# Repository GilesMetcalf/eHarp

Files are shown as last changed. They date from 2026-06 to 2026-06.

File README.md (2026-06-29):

# Lughnasadh eHarp
This is the ongoing eHarp project. 

## feature summary
The eharp is a full-featured MIDI controller that offers the following functions:
- Up to 32 notes that can be played
- Fully polyphonic
- A choice of 23 different scales (modes)
- A choice of MIDI channels
- Transposition from -6 to +6 intervals. Essentially any key in the octave.
- Selectable octave settings from -3 to +3
- 11 selectable velocity settings
- Pitch and Bend controls
- Sustain pedal input
- Multi-level menu system
- Self-calibration to compensate for background light levels
- Several self-diagnostic features

## Architecture and principles
The eHarp is based on a scanned matrix of small lasers to detect an interruption to the beam (by sticking fingers into the beam!). The interruption is detected by a phototransistor which feeds an baseline-compensated analogue level amplifier and a digital comparator. A microcontroller (a Raspberry Pi Pico 2) runs CircuitPython code to detect the interruption, identify which laser is on at the time, makes appropriate adjustments depending on the selected scale, velocity, bend value and transposition, and them emits MIDI messages to whatever device is on the end. 

The lasers are small 5mW diodes (such as are used in laser pointers), scanned sequentially by the microcontroller. Only "active" diodes are scanned, so any which are not part of the scale, or that have been identified as blocked or faulty by the calibration routines are not illuminated and are skipped from the scan. This reduces any latency in generating notes, as well as preventing spurious notes playing.

## Boot and run sequences
### Boot up and calibration
On initially powering the eHarp up, the (numerous) I/O ports are initialised and the baseline offset output set to a default value of approximately 150mV. A flag is set to prevent any MIDI output (this stops random notes playing during calibration). A nice splash screen is displayed for a few seconds. This serves no purpose other than being flash, and can be aborted by pressing any button on the menu panel. The software twiddles it's little digital thumbs while this is displayed.
Once the splash expires, the eHarp drops into it's automated calibration routine. There are two elements to this. Firstly the baseline offset is adjusted to allow for the current ambient light by reading the sensor output (post amplification) with no lasers on. The offset voltage is adjusted to approximately 30-50mV above zero to give a bit of stability. 
Following the offset adjustment, all the lasers are scanned to check that they are producing an output and that the sensor is detecting them. (This assumes that there are no fingers in the way for this part!) Any which fail for any reason (poor and failing output - always a danger with cheap laser diodes! - misalignments or blockages, etc.) are marked as inactive and removed from normal scans. 
Finally, the main menu is displayed and the main scan routines are initiated.

### Run cycle
The run cycle essentially runs forever, and consists of three elements:
- The menu buttons are scanned. If any have been pressed, the menu subsystem executes whatever menu option is selected. This might be to change to a submenu, reset a state value (such as scale or key), or execute a calibration or diagnostic function. Once the action has been carried out, the menu returns to the parent level (or the main level, depending where it is in the heirarchy), and normal scanning continues.
- The laser matrix is scanned. All the available cells (0 to 31) are processed in sequence, and for each cell if the selected scale array and active note array both indicate that the cell is valid, the laser is illuminated. The sensor input is read, and if the beam is interrupted the current MIDI state for that note is checked. There are several possible outcomes at this stage:
  - The beam is not interrupted and the note is not active; do nothing and move on to the next cell.
  - The beam is not interrupted but the note was active; emit a <samp>NoteOff</samp> MIDI message.
  - The beam is interrupted and the note was active; do nothing and move on to the next cell.
  - The beam is interrupted and the note was not active; emit a <samp>NoteOn</samp> MIDI message.
- Once the cell has been  processed, the laser is turned off and the sequence moves to the next cell.
- Finally, once all the cells have been processed, the MIDI state (bend/mod controls and octave selection buttons) are scanned. Any changes are detected and state variables set accordingly. The bend and mod controls are analogue inputs from a joystick and are captured using the Pico's built-in ADC.

### MIDI generation
For each MIDI note generation event, before the <samp>NoteOn</samp> event is emitted, some adjustments and enhancements are needed. The <samp>NoteOn</samp> event contains several parameters:
- The actual note number, which is calculated from the cell number (0 to 31) plus the MIDI offset to get to the actual note (C3 for the bottom note). This is then appended with the transposition value (-6 to +6) and the octave value to give the required note.
- The velocity value (how hard the 'key' has been struck). This comes from the selected velocity value
- The MIDI channel number. This comes from the selected channel value.
  
On top of that, there are some MIDI control events that also need to be emitted, although these are not directly associated with a specific note:
- If the Bend control value has changed, a <samp>PitchBend</samp> event is emitted.
- If the Mod control value has changed, a <samp>ControlChange(1)</samp> event is emitted.
- If the Sustain pedal is pressed, a <samp>ControlChange(64)</samp> event is emitted with a parameter of 127 (sustain on).
- If the Sustain pedal is released, a <samp>ControlChange(64)</samp> event is emitted with a parameter of 0 (sustain off).

*My thanks also to Adam Metcalf for the original inspiration, as well as much sage advice during the design and build of this project (and not laughing at my terrible electronics!)*

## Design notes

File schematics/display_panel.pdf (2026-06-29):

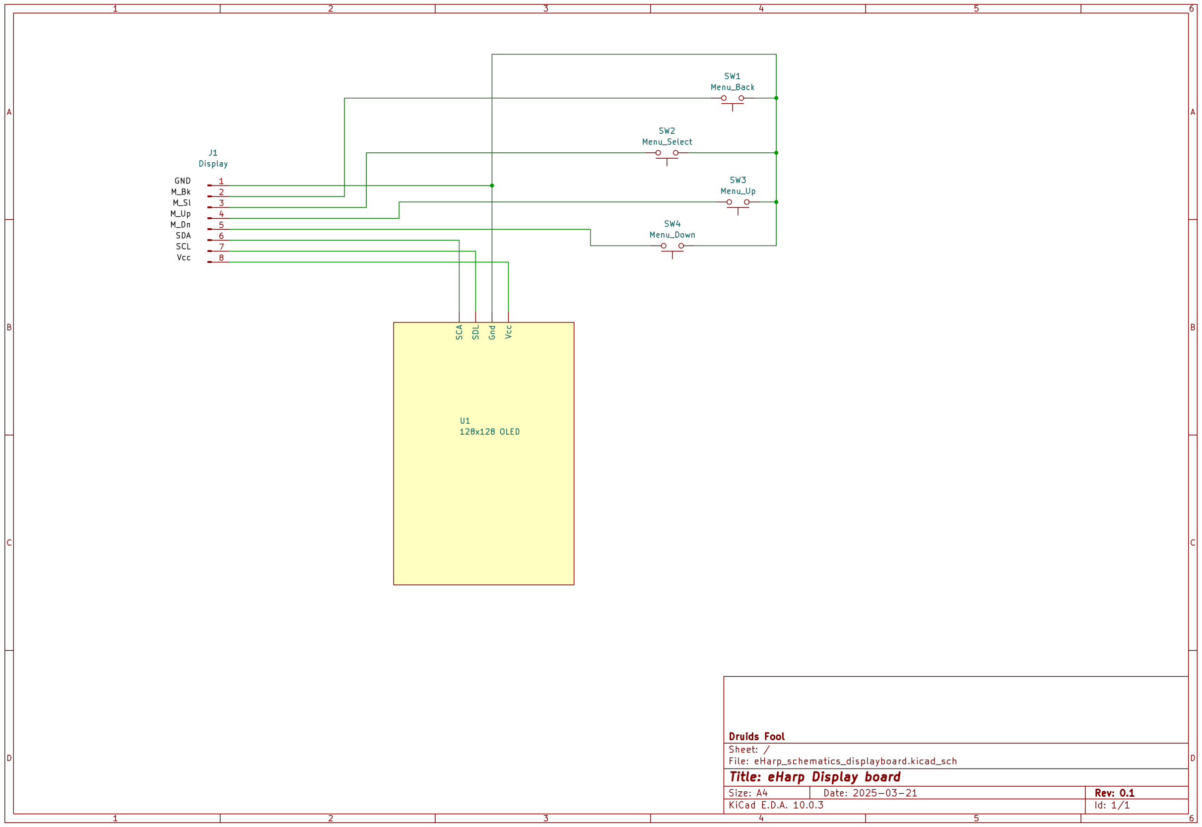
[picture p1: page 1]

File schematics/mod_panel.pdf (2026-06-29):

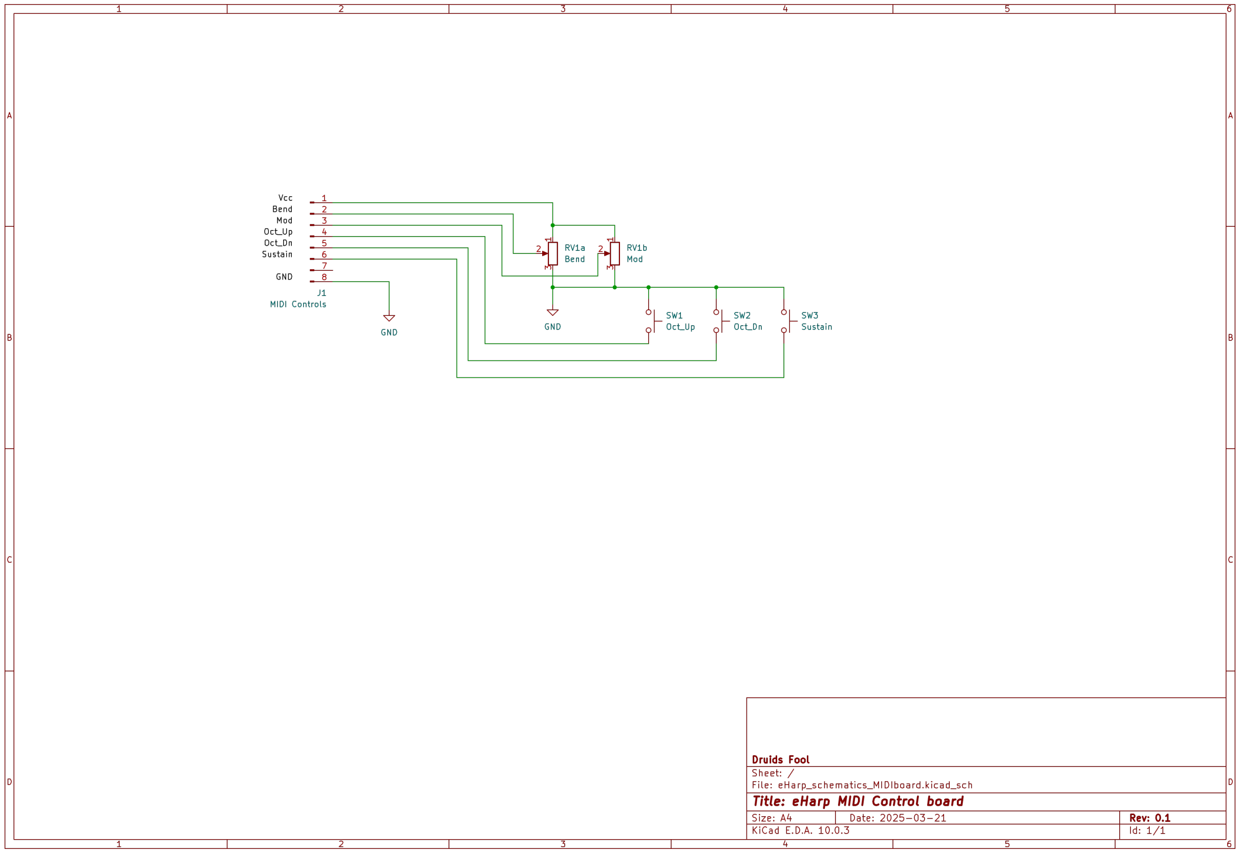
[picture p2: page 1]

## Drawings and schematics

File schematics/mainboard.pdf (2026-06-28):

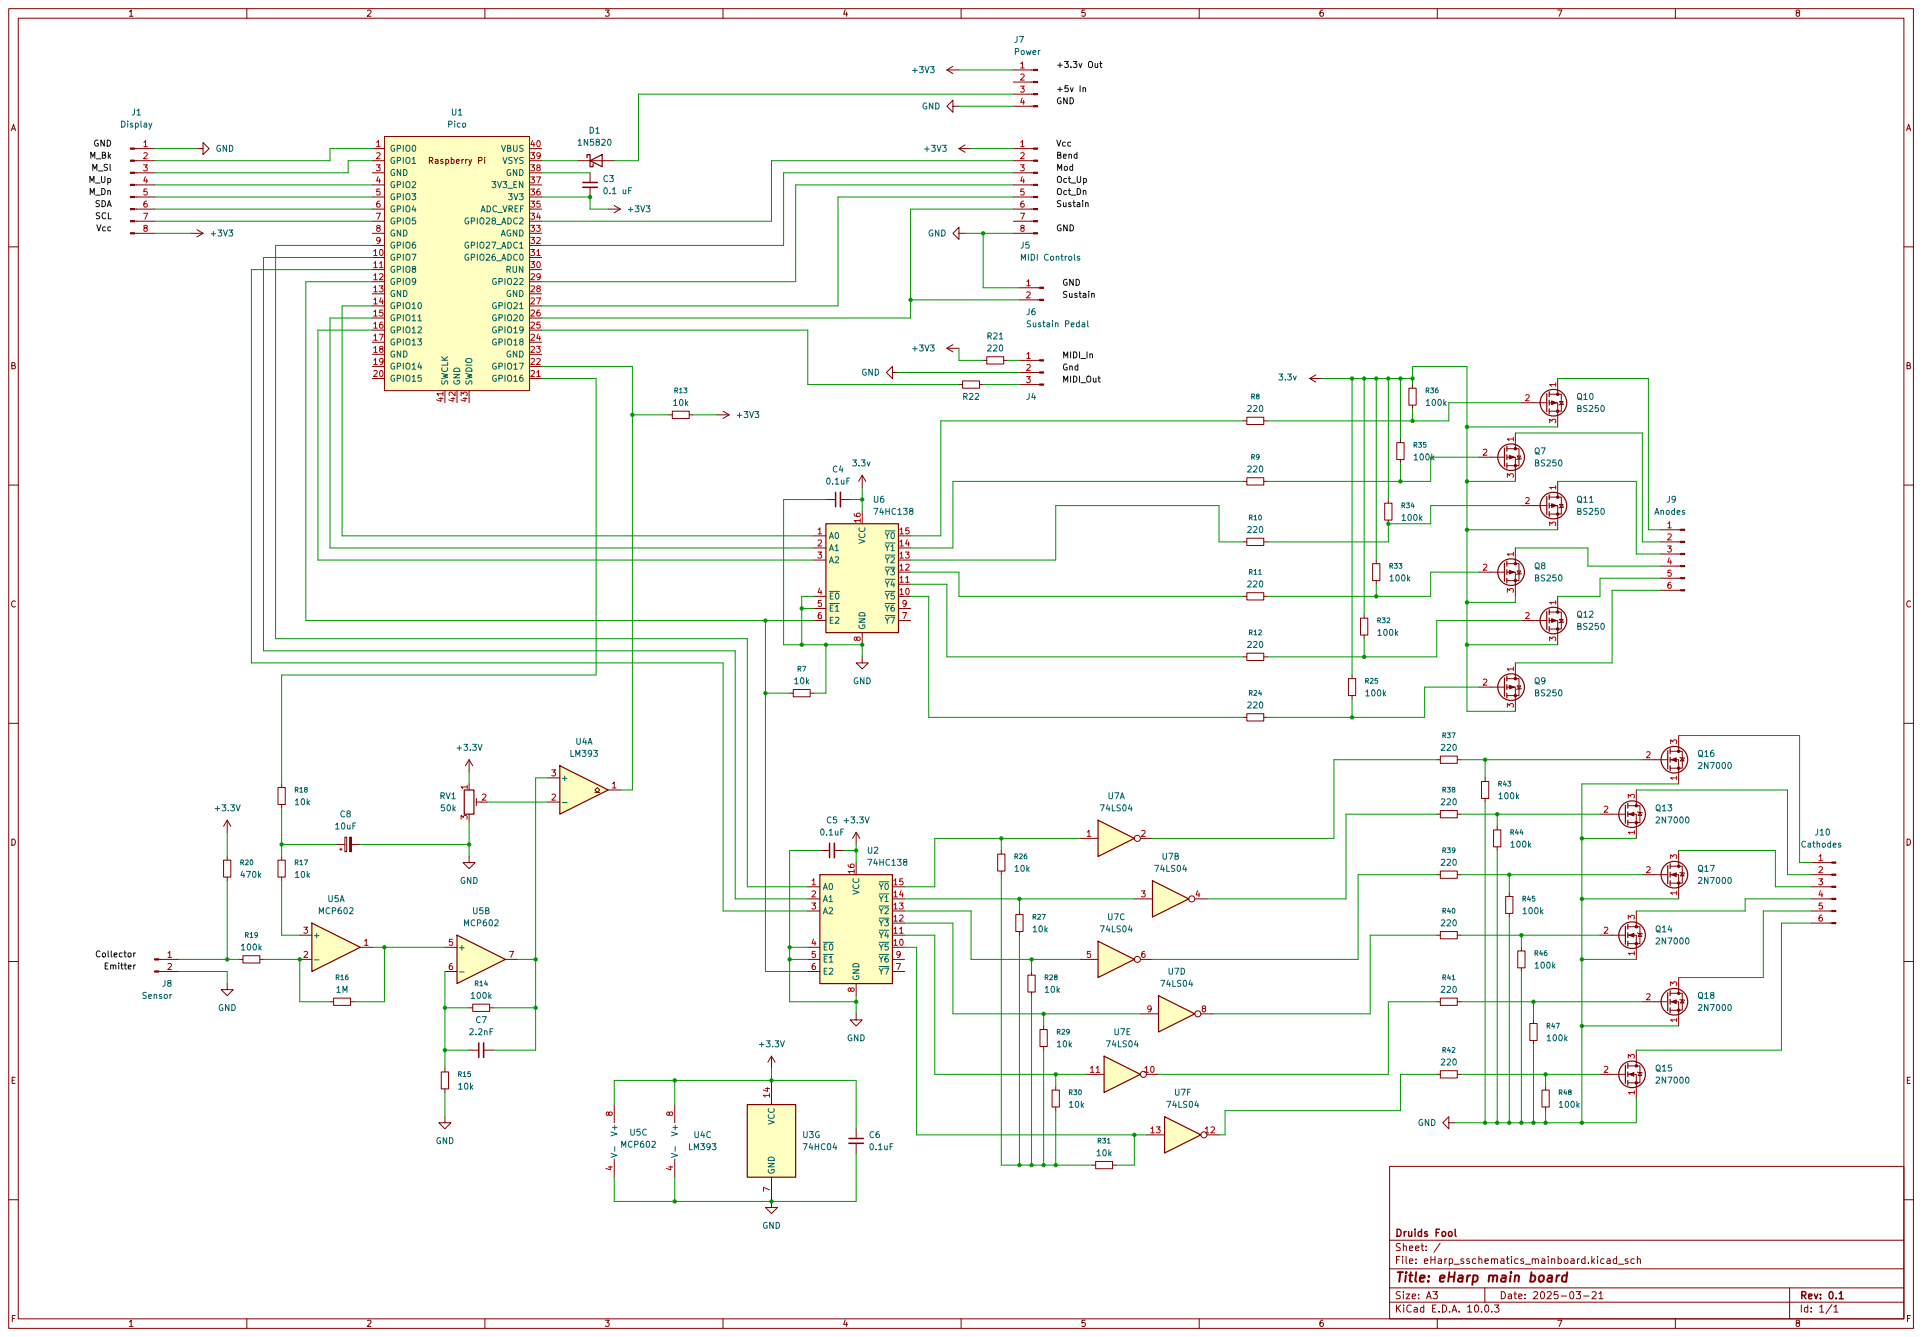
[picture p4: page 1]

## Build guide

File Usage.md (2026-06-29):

# Using the eHarp

## IMPORTANT SAFETY NOTE!!!
This instrument uses lasers. Lots of lasers!
Although the laser diodes are relatively low power (<5mW), they are still sufficient to cause eye injury if stared into. DO NOT LOOK DIRECTLY INTO THE LASER ARRAY!

## The menus
There are a number of menus available that allow the user to select various settings for playing, as well as giving access to some diagnostic and calibration features.

### Scales menu
There are 23 different scales or modes that can be selected from the **Scales** menu:
- Chromatic
- Major
- Minor
- Lydian
- Aeolian
- Super Locrian
- Augmented
- Bebop Dominant
- Blues
- Dorian
- Double Harmonic
- Enigmatic
- Flamenco
- Gypsy
- Half Diminished
- Harmonic Major
- Harmonic Minor
- Istrian
- Locrian
- Lydian Augmented
- Lydian Diminished
- Mixolydian
- Phrygian

Selecting one of these modes will restrict the MIDI output to only notes within that scale. Other notes and incidentals will not play.

### Tuning menu
The eHarp is naturally tuned to C (that is, the lowest note is C3). The tuning menu will allow transposition to any other key in semitones. That will also apply to any mode or scale that has been selected.

### Channel menu
This control selects the MIDI channel that messages are output on. By default, this is set to channel 0, but any channel up to 10 can be selected. Currently, it is not possible to select "all", although this may be implemented in the future.

### Velocity menu
MIDI velocity is a numerical representation of how hard a note is hit. Since this is not something that can be physically implemnted for interrupting a light beam, the **Velocity** menu allows the user to manually select one of 11 different velocity settings between 8 (really soft) and 127 (really hard). The default value is 64.

### Diagnostics menu
The **Diagnostics** menu provides access to a number of further features for recalibrating the eHarp, and some options that can be used when diagnosing issues or setting up the eHarp.

- _Calibration:_  This option reruns the automated calibration and valid note checks. It can be used if notes stop working, or notes play unasked. 
- _Slow Scan:_  This performs a slow scan of all the lasers in the array 5 times. It can be used to determine if all the laser diodes are working, as well as for setting the threshold for the comparator. MIDI messages will not be generated during this process, so no notes will play.
- _Single Step:_  Each laser is lit one at a time. The *"menu up"* and *"menu down"* buttons will step on to the next laser in the array. The *"menu back"* button will abort this process and return to the **Diagnosics** menu. MIDI messages will not be generated during this process, so no notes will play.
- _Mute Lasers:_  This option turns off all the lasers and precvents scanning for up to 1 minute. This is useful when setting the comparator threshold. At the end of the minute, or if any menu button is pressed before that, the process is aborted and the user returned to the **Diagnostics** menu.

Once all diagnostics have been completed, pressing the *"menu back"* button will return to the main menu, and normal operations will continue.

## The MIDI mod and octave controls
The **MOD** panel provides controls for changing the notes wheil playing.

### Octave buttons
The *Octave up* and *Octave down* buttons allow the user to transpose the output up or down full octaves (up to three octaves up or down from the nornal value, or between C1 to C6 for the lowest note). Scale/mode choice and any transposition remain unchanged when the octave is changed. 

### Mod/Bend control
The joystick performs three functions when playing. In one direction (marked on the panel) it bends the note playing up or down. In this fashion it performs in the same way as a Pitch Bend wheel on a normal keyboard.
In the orthogonal direction, the joystick acts as a Mod wheel, applying any modification (such as filter changes or vibrato) defined by the MIDI instrument being controlled. The **Mod** control is slightly different from the **Bend** control in that it works in the same way whichever way it is pushed.

Finally, If the joystick is pushed in, this turns on the sustain in the same way as using a sustain pedal.

## Connections
Three connections are provided.

### USB connection
The USB connection is used for both powering the eHarp, as well as providing a MIDI-over-USB communications with the MIDI instrument being used. This might be a DAW or a VST host, but equally it might be a hardware instrument such as a synth. Some sort of MIDI routing might be required (such as MIDIDash) to make sure that the messages appear where they should. This is dependent on your setup.

### MIDI output
There is also a 5-pin DIN standard MIDI connector in the schematic. I have not yet configured this in the software, but this will eventually mirror the USB MIDI output for more conventional connections.

### Sustain pedal
There is a 1/4-inch jack socket for a standard normally-off sustain pedal.

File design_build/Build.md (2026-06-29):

# Building the eHarp

This is not a detailed construction guide, more a loose description of the approach I took with the prototype!

## The body
The main body of the eHarp is built from four layers of ply. Two sheets of 600x1220mm ply were obtained from my local DIY store; a sheet of 12mm and a sheet of 20mm. I could get two 
body sections from each sheet (see cutting_plan.svg for the layout). These can be cut out with a jigsaw; I used a *big* bandsaw (you won't be able to do it with a small benchtop bandsaw!). It is also easier to make a template from some light ply for marking this out. The template has a couple of functions; it ensures that all your ply sections are the same shape and size, and it also comes in useful later one when you are aligning all those little laser diodes in the array. More on that later.
The 12mm sections form the inner core of the body. Before gluing them together, cut out the rectangular openings marked in red on the diagram for the controls - note that the larger opening is on one section only! Glue and clamp.
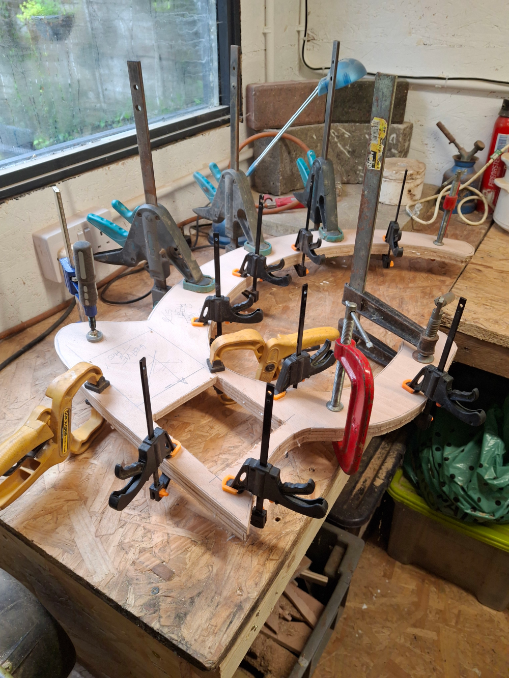
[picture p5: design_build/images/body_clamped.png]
(image) Body glued and clamped


Cut out the outer sections from the 20mm ply in the same way. Put them aside until later.
Once the core is glued, cut out a section for the laser array on the longer arm (keep the bit you cut out - you'll need it later), and a section for the sensor at the end of the shorter arm. Again, these are marked in red on the diagram. Use a router to cut channels for the cables for the laser array and the sensor to the electronics bay (the larger opening) in the core section.

The outer sections of 20mm ply can now be glued on and clamped. It is worth laying some cord into the routed channels before doing this. It makes pulling the cables through a lot easier, and prevents a lot of poking with bits of stiff wire and swearing later! Just be careful not to catch the cord between the layers of ply and gluing it permanently into place!
Once everything is glued and dried, the edges can be routed round, any nasty gaps filled, and the whole thing sanded smooth. Finish it with whatever finish takes your fancy. I did mine with a metallic red paint, and a light dusting of an iridescent spray. The whole thing was then given several coats of a hard-wearing varnish (I know how much things can get knocked about!).

## The laser array
This is where that bit you saved (you *did* save it, didn't you?) comes in. It will need to be cut down a little further to leave you with a curved section about 2cm wide on the inside of the curve. Cut a couple of cm off each end as well to allow space to fit it later. Measure the length of the outside curve of the piece, allow another centimeter or so for space, and divide the remainder by 32. This will give you the spacing of the individual laser diodes. Use a pair of dividers to mark off the locations along the edge. 
Draw lines at *exactly* 90 degrees to the edge toward the inner curve. These are the drill guides that you will be using to make the holes for the diodes. Also draw a line along the exact middle of the inner curve.
Measure the diameter of the diode module (mine were 6mm) and using a *sharp* drill bit 0.5mm wider, drill holes from inside curve to outside curve along the guidelines for all 32 diodes. Use a pillar drill, and it's probably worth making a little jig to help with this. You won't be able to do it accurately with a hand drill!

How you assemble the array is up to you, but in my case I found it easiest to take it one diode at a time, testing, aligning and securing each one before moving on to the next one. The diodes I used were 3.3v ones, and you will need a suitable power supply or battery with crocodile clips so that you can power up each diode before soldering it in to anything.
Remember I said that that plywood template would come in useful? Clamp or use double-sided tape to affix the drilled plywood array section to the long arm of the template, and attach a small target (a small round bit of wood, or a pen cap) to the centre of the end of the short arm. Now, for each laser:
- Connect it to the supply. Make sure that the polarity is correct and watch your eyes!
- Check the focus and brightness. When buying in bulk, some diodes can be pretty dim and often out of focus. The lens end can be twisted to focus the beam.
- Put the diode in place in it's hole. If you drilled accurately it should be fairly close to your target. You can wiggle it a bit to get it properly aimed.
- Once aimed, fix it in place with a small drop of thin superglue. Apply the glue to the back, *not* the front (you get glue on the lens otherwise and obscure the beam - don't ask me how I know this!).

The array can be wired. The leads from the diodes are very thin and flimsy, so it is worth keeping them as short as possible, and don't connect them directly to any flying leads for connecion to the main board. Provide some fixed connection points next to the diodes and use those. I found some small copper tacks that worked admirably. If using tacks like this, drill the wood with a small drill and push them in - don't hammer them! Complete the wiring with ribbon cable, and leave enough to reach the main board easily.

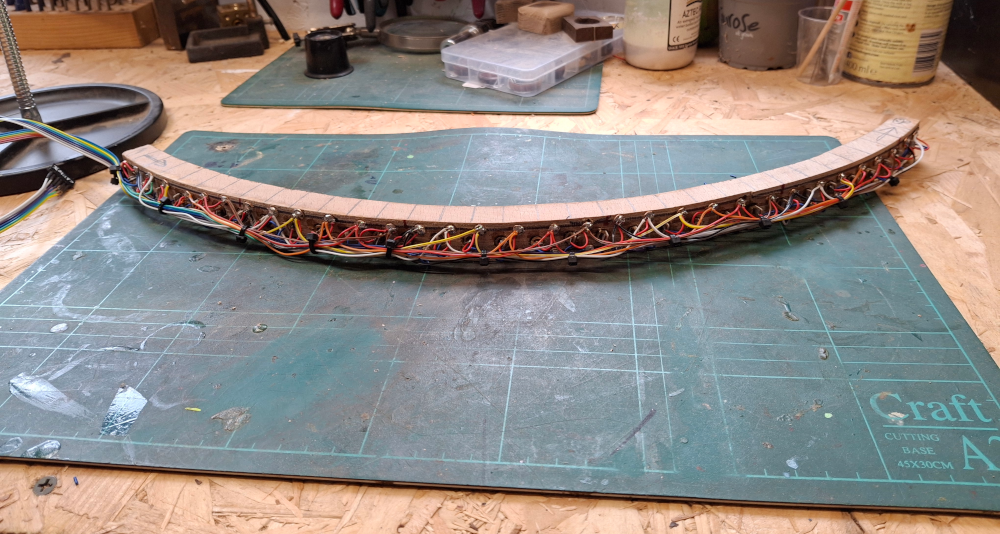
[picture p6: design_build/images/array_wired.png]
(image) Laser array diodes in place

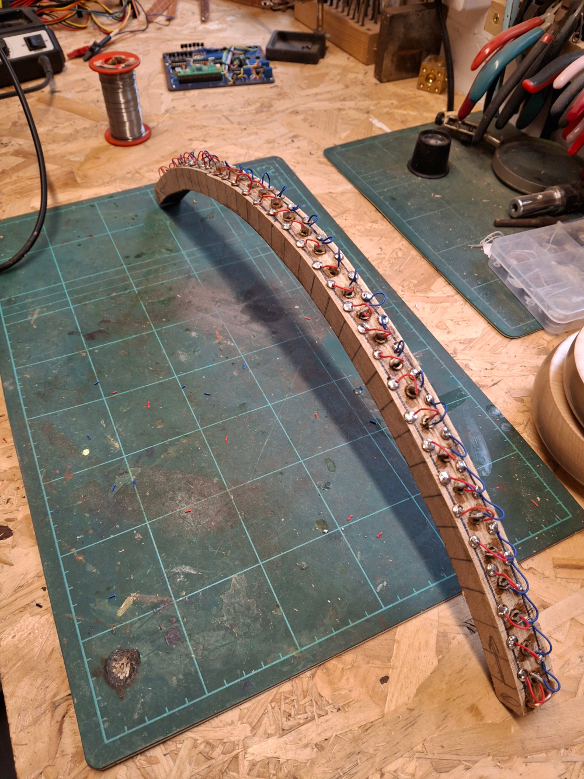
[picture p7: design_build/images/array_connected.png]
(image) Laser array wired up


## The sensor
The laser sensor is a bit simpler to put together. It was made from a stack of four units cut from 6mm clear acrylic (there is a template in the drawings). Once cut, the segments were glued together using UV-curing glue, and clamped before curing to remove any air bubbles. Once glued, the stack was sanded down to 8000 grit and then polished with cutting compound to get a glassy finish.
In order to maximise light capture it is worth putting some sort of reflective finish on all faces except the front-facing curved face. I used silver leaf, but a reflective silver paint will work too. Mask off the front face before gilding/painting to prevent anything getting on that face.

Once the acrylic block is finished, drill a 6mm hole from one of the flat sides to the centre of the segment. Shorten the leads of a PT334-6C phototransistor and solder a length of coaxial cable on (braid to emitter, core to collector). Use heat-shrink sleeving to insulate the joints. You could use normal cable. but the levels are very low and you may pick up a lot of noise. Coax will reduce this.
Insert the phototransistor into the hole you drilled and secure in place with UV-curing glue.

## The panels
There are three control panels, a menu/display one, a bend/mod and octave selection one, and a connector panel for the interfaces and power. The construction principles are the same for each.
Each panel is made from two layers of 2mm acrylic, laser-cut to shape. All the cutting guides for these are in the diagrams. I have also provided the labels for these panels here. These can be printed out and sandwiched between the layers of acrylic.
I built the circuitry for the panels on stripboard (as this is a prototype). It would be nicer to user proper PCBs.
Again, flying ribbon cables should be attached with sufficient length to reach the electronics bay.

## The main board
All the circuitry was built on one prototyping board (well, it was a prototype!) that fits into the electorincs bay. Again, it would be nicer to use a proper PCB, but this has been through many iterations and I did not want a huge pile of useless boards cluttering up my workshop!
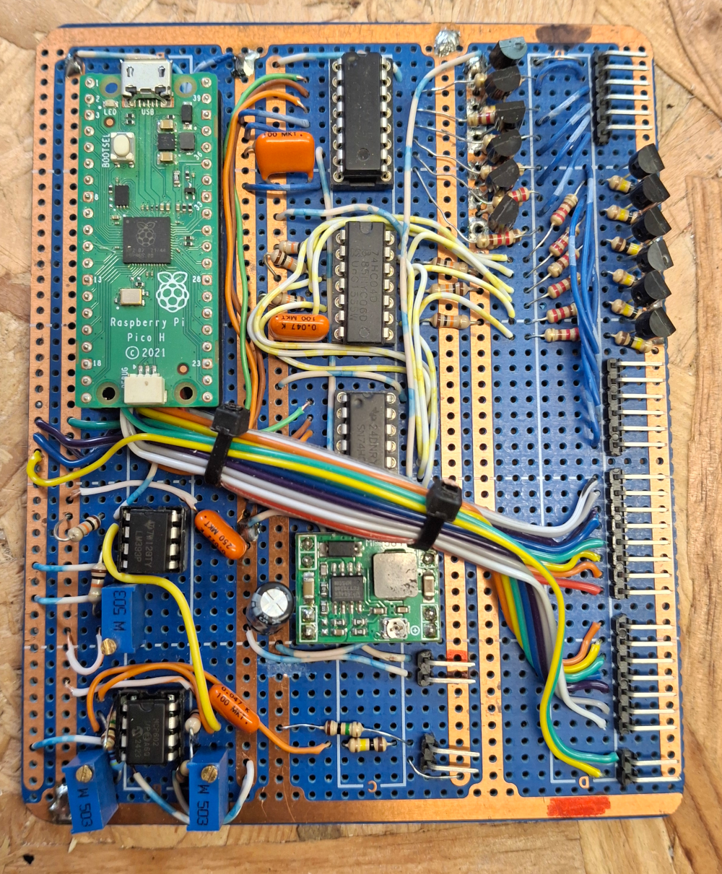
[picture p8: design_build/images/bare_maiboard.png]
(image) The mainboard


## Assembly
The sensor was placed in the short arm of the eHarp, and glued in place using 2-part epoxy.

The cables for the laser array were drawn through the channel using the previously placed cord, and then the array located in place so that the lowest note (first laser in the array) is towards the base of the harp, and the highest at the top end of the arm. The array is lightly placed initially, as it may need to be repositioned slightly to aim them at the sensor correctly.
The various panels are put in place and secured with small brass screws. All the leads are brought out to the electronics bay (which is now sprouting a bewildering nest of cables! You *did* mark them before putting everything in place, didn't you?).

Finally, the main board is connected and nestled in the electronics bay. 
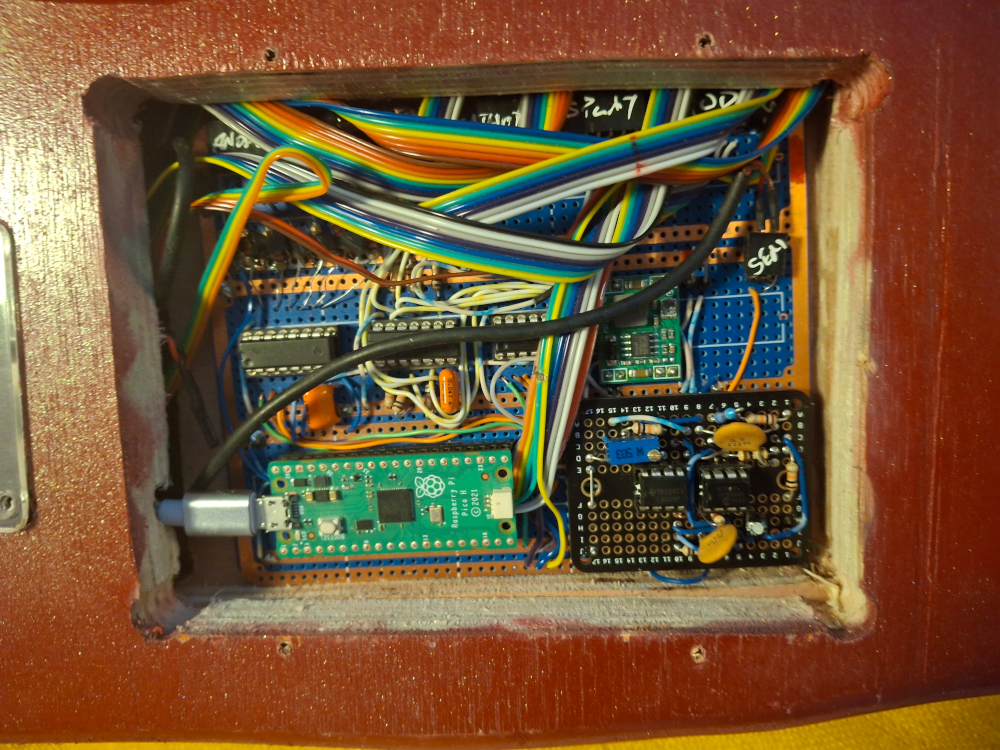
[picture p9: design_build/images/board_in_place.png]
(image) The mainboard in place

Connect up the USB cable to a supply and let it boot up. Once it has finished booting, use the Slow Scan option in the Diagnostics menu to finish aligning the laser array. It can be pressed into place, and secured with a drop of glue if necessary (it should be a tight push fit, and not need glue).

## Final adjustment
There is one small adjustment that will be needed, and this will require an oscilloscope or a logic analyser. This should be attached to the output of the LM393 comparator (U5 on the schematic). Select Mute Lasers from the Diagnostics menu (this will turn off all the lasers) and set RV1 to give a LOW output.
Now select Slow Scan from the Diagnostics menu and tweak RV1 to give a HIGH output for each laser.

[body_clamp]: https://github.com/GilesMetcalf/eHarp/tree/main/design_build/images/body_clamped.png "(image) Body glued and clamped"
[array_wired]: https://github.com/GilesMetcalf/eHarp/tree/main/design_build/images/array_wired.png "(image) Laser array diodes in place"
[array_connected]: https://github.com/GilesMetcalf/eHarp/tree/main/design_build/images/array_connected.png "(image) Laser array wired up"
[mainboard]: https://github.com/GilesMetcalf/eHarp/tree/main/design_build/images/bare_maiboard.png "(image) The mainboard"
[board_placed]: https://github.com/GilesMetcalf/eHarp/tree/main/design_build/images/board_in_place.png "(image) The mainboard in place"

You're all done! All that is needed is a cover over the electronics bay. I used a small piece of 3mm ply, coloured to match the rest of the body, and secured with small brass screws.
Connect it to your favourite DAW or VST host and enjoy!

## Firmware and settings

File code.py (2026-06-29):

# eHarp in CircuitPython

# +-------------------------------+
# |   *** eHarp v2.0 Project ***  |
# |                               |
# | Author:         Gil Metcalf   |
# | Code version:   2.10.8        |
# | Date:           28-Jun-2026   |
# | Licence :       GPL v3.0      |
# +-------------------------------+

import board
import displayio
import terminalio
from adafruit_display_text import label
import adafruit_displayio_sh1107
import busio
import digitalio
import time
import analogio
import pwmio
import usb_midi
import adafruit_midi
from adafruit_midi.note_on import NoteOn
from adafruit_midi.note_off import NoteOff
from adafruit_midi.pitch_bend import PitchBend
from adafruit_midi.control_change import ControlChange
import config

# +------------------------------+
# | Constants and menu constants |
# +------------------------------+

# IO ports (menu buttons)
button_up = digitalio.DigitalInOut(board.GP2)
button_up.direction = digitalio.Direction.INPUT
button_up.pull = digitalio.Pull.UP
button_dn = digitalio.DigitalInOut(board.GP3)
button_dn.direction = digitalio.Direction.INPUT
button_dn.pull = digitalio.Pull.UP
button_bck = digitalio.DigitalInOut(board.GP0)
button_bck.direction = digitalio.Direction.INPUT
button_bck.pull = digitalio.Pull.UP
button_sel = digitalio.DigitalInOut(board.GP1)
button_sel.direction = digitalio.Direction.INPUT
button_sel.pull = digitalio.Pull.UP

# IO ports (MIDI controls)
button_oct_up = digitalio.DigitalInOut(board.GP22)
button_oct_up.direction = digitalio.Direction.INPUT
button_oct_up.pull = digitalio.Pull.UP
button_oct_dn = digitalio.DigitalInOut(board.GP21)
button_oct_dn.direction = digitalio.Direction.INPUT
button_oct_dn.pull = digitalio.Pull.UP
button_stn = digitalio.DigitalInOut(board.GP19)
button_stn.direction = digitalio.Direction.INPUT
button_stn.pull = digitalio.Pull.UP
mod_in = analogio.AnalogIn(board.A1)
bend_in = analogio.AnalogIn(board.A2)

# IO ports (note scanning)
row_s0 = digitalio.DigitalInOut(board.GP10)
row_s0.direction = digitalio.Direction.OUTPUT
row_s1 = digitalio.DigitalInOut(board.GP11)
row_s1.direction = digitalio.Direction.OUTPUT
row_s2 = digitalio.DigitalInOut(board.GP12)
row_s2.direction = digitalio.Direction.OUTPUT
col_s0 = digitalio.DigitalInOut(board.GP6)
col_s0.direction = digitalio.Direction.OUTPUT
col_s1 = digitalio.DigitalInOut(board.GP7)
col_s1.direction = digitalio.Direction.OUTPUT
col_s2 = digitalio.DigitalInOut(board.GP8)
col_s2.direction = digitalio.Direction.OUTPUT
scan_in = digitalio.DigitalInOut(board.GP17)
scan_in.direction = digitalio.Direction.INPUT
scan_in.pull = digitalio.Pull.UP
lsr_enbl = digitalio.DigitalInOut(board.GP9)
lsr_enbl.direction = digitalio.Direction.OUTPUT

# IO ports (analogue input control)
baseline_in = analogio.AnalogIn(board.A0)
baseline_out = pwmio.PWMOut(board.GP18, frequency=500)

# Scanning constants
num_notes = config.NUM_NOTES
output_enable = False # Disable MIDI note generation for setup and calibration

# Menu handling constants
button_pressed = [0,0,0,0]
last_button_state = [0,0,0,0]

# State values
state_menu = 0
state_scale = 0
state_tune = 6
state_channel = 1
state_octave = 0
state_velocity = 6

# Menus
scales = [
  "Chromatic",
  "Major",
  "Minor",
  "Lydian",
  "Aeolian",
  "Super Locrian",
  "Augmented",
  "Bebop Dominant",
  "Blues",
  "Dorian",
  "Double Harmonic",
  "Enigmatic",
  "Flamenco",
  "Gypsy",
  "Half Diminished",
  "Harmonic Major",
  "Harmonic Minor",
  "Istrian",
  "Locrian",
  "Lydian Augmented",
  "Lydian Diminished",
  "Mixolydian",
  "Phrygian"
]

tuning = ["-6", "-5", "-4", "-3", "-2", "-1", "0", "1", "2", "3", "4", "5", "6"]

channel = ["0", "1", "2", "3", "4", "5", "6", "7", "8", "9", "10"]

velocity = ["8", "16", "24", "32", "48", "64","72", "80", "96", "112", "127"]

system_menu = ["Calibration", "Slow Scan", "Single Step", "Mute lasers"]

# Mapping scales
scale_map = [
  [1,1,1,1,1,1,1,1,1,1,1,1,1,1,1,1,1,1,1,1,1,1,1,1,1,1,1,1,1,1,1,1,1,1,1,1],  # Chromatic
  [1,0,1,0,1,1,0,1,0,1,0,1,1,0,1,0,1,1,0,1,0,1,0,1,1,0,1,0,1,1,0,1,0,1,0,1],  # Major
  [1,0,1,1,0,1,0,1,0,0,1,1,1,0,1,1,0,1,0,1,0,0,1,1,1,0,1,1,0,1,0,1,0,0,1,1],  # Minor
  [1,0,1,0,1,0,1,1,0,1,0,1,1,0,1,0,1,0,1,1,0,1,0,1,1,0,1,0,1,0,1,1,0,1,0,1],  # Lydian
  [1,0,1,1,0,1,0,1,1,0,1,0,1,0,1,1,0,1,0,1,1,0,1,0,1,0,1,1,0,1,0,1,1,0,1,0],  # Aeolian
  [1,1,0,1,1,0,1,0,1,0,1,0,1,1,0,1,1,0,1,0,1,0,1,0,1,1,0,1,1,0,1,0,1,0,1,0],  # Super Locrian
  [1,0,0,1,1,0,0,1,1,0,0,1,1,0,0,1,1,0,0,1,1,0,0,1,1,0,0,1,1,0,0,1,1,0,0,1],  # Augmented
  [1,0,1,0,1,1,0,1,0,1,1,1,1,0,1,0,1,1,0,1,0,1,1,1,1,0,1,0,1,1,0,1,0,1,1,1],  # Bebop Dominant
  [1,0,0,1,0,1,1,1,0,0,1,1,1,0,0,1,0,1,1,1,0,0,1,1,1,0,0,1,0,1,1,1,0,0,1,1],  # Blues
  [1,0,1,1,0,1,0,1,0,1,1,0,1,0,1,1,0,1,0,1,0,1,1,0,1,0,1,1,0,1,0,1,0,1,1,0],  # Dorian
  [1,1,0,0,1,1,0,1,1,0,0,1,1,1,0,0,1,1,0,1,1,0,0,1,1,1,0,0,1,1,0,1,1,0,0,1],  # Double Harmonic
  [1,1,0,0,1,0,1,0,1,0,1,1,1,1,0,0,1,0,1,0,1,0,1,1,1,1,0,0,1,0,1,0,1,0,1,1],  # Enigmatic
  [1,1,0,0,1,1,0,1,1,0,0,1,1,1,0,0,1,1,0,1,1,0,0,1,1,1,0,0,1,1,0,1,1,0,0,1],  # Flamenco
  [1,0,1,1,0,0,1,1,1,0,1,0,1,0,1,1,0,0,1,1,1,0,1,0,1,0,1,1,0,0,1,1,1,0,1,0],  # Gypsy
  [1,0,1,1,0,1,1,0,1,0,1,0,1,0,1,1,0,1,1,0,1,0,1,0,1,0,1,1,0,1,1,0,1,0,1,0],  # Half Diminished
  [1,0,1,0,1,1,0,1,1,0,0,1,1,0,1,0,1,1,0,1,1,0,0,1,1,0,1,0,1,1,0,1,1,0,0,1],  # Harmonic Major
  [1,0,1,1,0,1,0,1,1,0,0,1,1,0,1,1,0,1,0,1,1,0,0,1,1,0,1,1,0,1,0,1,1,0,0,1],  # Harmonic Minor
  [1,1,0,1,1,0,1,1,0,0,0,0,1,1,0,1,1,0,1,1,0,0,0,0,1,1,0,1,1,0,1,1,0,0,0,0],  # Istrian
  [1,1,0,1,0,1,1,0,1,0,1,0,1,1,0,1,0,1,1,0,1,0,1,0,1,1,0,1,0,1,1,0,1,0,1,0],  # Locrian
  [1,0,1,0,1,0,1,0,1,1,0,1,1,0,1,0,1,0,1,0,1,1,0,1,1,0,1,0,1,0,1,0,1,1,0,1],  # Lydian Augmented
  [1,0,1,1,0,0,1,1,0,1,0,1,1,0,1,1,0,0,1,1,0,1,0,1,1,0,1,1,0,0,1,1,0,1,0,1],  # Lydian Diminished
  [1,0,1,0,1,1,0,1,0,1,1,0,1,0,1,0,1,1,0,1,0,1,1,0,1,0,1,0,1,1,0,1,0,1,1,0],  # Mixolydian
  [1,1,0,1,0,1,0,1,1,0,1,0,1,1,0,1,0,1,0,1,1,0,1,0,1,1,0,1,0,1,0,1,1,0,1,0]   # Phrygian
]

# MIDI constants and variables
midi = adafruit_midi.MIDI(midi_out=usb_midi.ports[1], out_channel=state_channel)
current_octave = 0
last_octave_up = 0
last_octave_down = 0
last_sustain = 0
last_mod = 0
last_bend = 0
note_active = [0 for i in range(num_notes)]
note_valid = [1 for i in range(num_notes)]

# Display constants
displayio.release_displays()
i2c = busio.I2C(board.GP5, board.GP4)  # Update pins if needed
display_bus = displayio.I2CDisplay(i2c, device_address=0x3C)
display = adafruit_displayio_sh1107.SH1107(display_bus, width=config.DISPLAY_WIDTH, height=config.DISPLAY_HEIGHT, display_offset=config.DISPLAY_OFFSET)
display.rotation = config.DISPLAY_ROTATION
display_window = config.DISPLAY_WINDOW


# +----------------------+
# | Laser scan functions |
# +----------------------+

def selectMuxChannel(s0, s1, s2, mux):
  s0.value = (mux & 0x01) > 0  # Set LSB
  s1.value = (mux & 0x02) > 0  # Set second bit
  s2.value = (mux & 0x04) > 0  # Set third bit

def selectLaser(cell):
  # Select and turn on the selected laser
  row = cell % config.NUM_ROWS
  col = cell // config.NUM_ROWS
  lsr_enbl.value = 0
  selectMuxChannel(row_s0, row_s1, row_s2, row)
  selectMuxChannel(col_s0, col_s1, col_s2, col)
  lsr_enbl.value = 1

def set_baseline():
  lsr_enbl.value = 0
  for _ in range(config.CALIBRATION_SCANS):
    base_mv = baseline_in.value / config.DCMV_RATIO
    time.sleep(config.BASE_SETTLE)
    if base_mv > config.BASE_OFFSET:
      offset = base_mv - config.BASE_OFFSET
      baseline_out.duty_cycle = int(offset * config.DCMV_RATIO)

def checkForValidNotes():
  global note_valid, note_active, output_enable
    # Reset everything
  note_active = [0 for i in range(num_notes)]
  note_valid = [1 for i in range(num_notes)]
    # Loop around the array and look for blocked/non-working lasers
    # Non-working notes will be ignored in scans so that they don't play continuously.
  output_enable = False
  for _ in range(config.CALIBRATION_SCANS):
    for cell in range(0,num_notes):
      selectLaser(cell)
      time.sleep(config.LASER_SETTLE) # Settle time
      current_sensor = scan_in.value
      if current_sensor == config.NOTE_ON_LOGIC:   # Laser is not reaching the sensor
        note_valid[cell] = 0    # Mark the note as dead
      else:
        note_valid[cell] = 1    # Mark the note as working
  # Back to main menu
  output_enable = True
  go_back()

def calibrate():
  set_baseline()
  checkForValidNotes()

def scanMatrix():
  # global note_valid, state_scale
  for cell in range(0,num_notes):
      if scale_map[state_scale][cell] == 1 and note_valid[cell] == 1:
        selectLaser(cell)
        time.sleep(config.LASER_SETTLE) # Settle time
        current_sensor = scan_in.value
        if (current_sensor == config.NOTE_ON_LOGIC and note_active[cell] == 0):
          note_active[cell] = 1
          testScale(cell)
        elif (current_sensor != config.NOTE_ON_LOGIC and note_active[cell] == 1):
          note_active[cell] = 0
          releaseNote(cell)

def slow_scan():
  # Slowly cycle round all lasers
  global output_enable
  output_enable = False
  for _ in range(0,config.SLOW_SCAN_COUNT):
    for cell in range(0,num_notes):
      selectLaser(cell)
      time.sleep(config.SLOW_SCAN_SPEED)
  # Back to main menu
  output_enable = True
  go_back()

def single_step():
  # Manually step through lasers
  global last_button_state
  this_step = 0
  while True:
    if button_up.value == 0 and last_button_state[0] == 0:
      last_button_state[0] = 1
      this_step += 1
      if this_step > num_notes - 1:
        this_step = num_notes - 1
    if button_dn.value == 0 and last_button_state[1] == 0:
      last_button_state[1] = 1
      this_step -= 1
      if this_step < 0:
        this_step = 0
    if button_bck.value == 0 and last_button_state[3] == 0:
      last_button_state[3] = 1
      break
    selectLaser(this_step)
    time.sleep(0.5) # Allow time to release the button!
    last_button_state[0] = 0
    last_button_state[1] = 0
    last_button_state[3] = 0
    lsr_enbl.value = 0  # Turn off any lasers
  go_back()

def mute_lasers():
  # Turn lasers off for up to 1 minute
  global output_enable
  output_enable = False
  lsr_enbl.value = 0
  start_time = time.monotonic()
  while time.monotonic() - start_time < config.MAX_MUTE_TIME:  # Press any button to continue...
    if not button_up.value:
      break
    if not button_dn.value:
      break
    if not button_sel.value:
      break
    if not button_bck.value:
      break
    time.sleep(0.05)
  output_enable = True
  lsr_enbl.value = 1


# +--------------------------+
# | Scale and MIDI functions |
# +--------------------------+
def set_scale(index):
  global state_scale
  state_scale = index
  scale_menu.pointer = index
  go_back()

def set_tune(index):
  global state_tune
  state_tune = index
  tuning_menu.pointer = index
  go_back()

def set_velocity(index):
  global state_velocity
  state_velocity = index
  velocity_menu.pointer = index
  go_back()

def set_channel(index):
  global state_channel
  state_channel = index
  channel_menu.pointer = index
  go_back()


# +----------------------------+
# | Menu and display functions |
# +----------------------------+

# Classes for menu handling
class Menu:
  def __init__(self, title, items, pointer = 0):
    self.title = title
    self.items = items
    self.pointer = max(0, min(pointer, len(items) - 1))
class MenuItem:
  def __init__(self, text, action=None, submenu=None):
    self.text = text
    self.action = action
    self.submenu = submenu


# Menu configuration
scale_menu = Menu(
  "Scales",
  [MenuItem(
    scale_name, action=lambda idx=i: set_scale(idx))
    for i, scale_name in enumerate(scales)
  ], state_scale)

tuning_menu = Menu(
  "Tuning",
  [MenuItem(
    tuning_value, action=lambda idx=i: set_tune(idx))
    for i, tuning_value in enumerate(tuning)
  ], state_tune)

channel_menu = Menu(
  "Channel",
  [MenuItem(
    channel_value, action=lambda idx=i: set_channel(idx))
    for i, channel_value in enumerate(channel)
  ], state_channel)

velocity_menu = Menu(
  "Velocity",
  [MenuItem(
    velocity_value, action=lambda idx=i: set_velocity(idx))
    for i, velocity_value in enumerate(velocity)
  ], state_velocity)

system_menu = Menu("Diagnostics", [
  MenuItem("Calibration", action=calibrate),
  MenuItem("Slow Scan", action=slow_scan),
  MenuItem("Single Step", action=single_step),
  MenuItem("Mute lasers", action=mute_lasers)
])

main_menu = Menu("Main", [
  MenuItem("Scale / Mode", submenu=scale_menu),
  MenuItem("Tuning", submenu=tuning_menu),
  MenuItem("MIDI Channel", submenu=channel_menu),
  MenuItem("Velocity", submenu=velocity_menu),
  MenuItem("Diagnostics", submenu=system_menu)
])

menu_stack = [main_menu]

def show_splash():
  splash_group = displayio.Group()
  bitmap = displayio.OnDiskBitmap(config.LOGO_FILE)
  tile_grid = displayio.TileGrid(bitmap, pixel_shader=bitmap.pixel_shader, x=0, y=-10)
  splash_group.append(tile_grid)
  display.root_group = splash_group
  start_time = time.monotonic()
  while time.monotonic() - start_time < config.SPLASH_TIME:  # Press any button to continue or timeout..
    if not button_up.value:
      break
    if not button_dn.value:
      break
    if not button_sel.value:
      break
    if not button_bck.value:
      break
    time.sleep(0.05)

def get_window(this_menu, this_pointer):
  item_count = len(this_menu)
  this_pointer = max(0, min(this_pointer, item_count - 1))
  start = (this_pointer // display_window) * display_window
  end = min(start + display_window, item_count)
  return start, end

def show_menu(menu, pointer):
  start, end = get_window(menu.items, pointer)
  menu_group = displayio.Group(x=-6, y=-16)
  for i in range(start, end):
    y_pos = 20 + ((i - start) * 12)
    item = menu.items[i]
    if i == pointer:
      bg_width = len(item.text) * 7
      bg_bitmap = displayio.Bitmap(bg_width, 10, 2)
      bg_palette = displayio.Palette(2)
      bg_palette[0] = 0xFFFFFF
      bg_palette[1] = 0x000000
      bg_tilegrid = displayio.TileGrid(
        bg_bitmap,
        pixel_shader=bg_palette,
        x=20,
        y=y_pos - 3
      )
      menu_group.append(bg_tilegrid)
      text_label = label.Label(
        terminalio.FONT,
        text=item.text,
        color=0x000000,
        x=20,
        y=y_pos + 2
      )
    else:
      text_label = label.Label(
        terminalio.FONT,
        text=item.text,
        color=0xFFFFFF,
        x=20,
        y=y_pos + 2
      )
    menu_group.append(text_label)
  display.root_group = menu_group

def step_up():
  current_menu = menu_stack[-1]
  current_menu.pointer += 1
  if current_menu.pointer > len(current_menu.items) - 1:
    current_menu.pointer = len(current_menu.items) - 1
  show_menu(current_menu, current_menu.pointer)

def step_down():
  current_menu = menu_stack[-1]
  current_menu.pointer -= 1
  if current_menu.pointer < 0:
    current_menu.pointer = 0
  show_menu(current_menu, current_menu.pointer)

def select_item():
  current_menu = menu_stack[-1]
  selected_item = current_menu.items[current_menu.pointer]
  if selected_item.submenu:
    menu_stack.append(selected_item.submenu)
    show_menu(selected_item.submenu, selected_item.submenu.pointer)
  elif selected_item.action:
     selected_item.action()

def go_back():
  if len(menu_stack) > 1:
    menu_stack.pop()
  current_menu = menu_stack[-1]
  show_menu(current_menu, current_menu.pointer)

def get_current_menu():
    return menu_stack[-1]

def test_menu_buttons():
  global last_button_state
  if button_up.value == 0 and last_button_state[0] == 0:
    last_button_state[0] = 1
    step_up()
  if button_dn.value == 0 and last_button_state[1] == 0:
    last_button_state[1] = 1
    step_down()
  if button_sel.value == 0 and last_button_state[2] == 0:
    last_button_state[2] = 1
    select_item()
  if button_bck.value == 0 and last_button_state[3] == 0:
    last_button_state[3] = 1
    go_back()
    # Button release debounce clearing
  if button_up.value == 1 and last_button_state[0] == 1:
    last_button_state[0] = 0
  if button_dn.value == 1 and last_button_state[1] == 1:
    last_button_state[1] = 0
  if button_sel.value == 1 and last_button_state[2] == 1:
    last_button_state[2] = 0
  if button_bck.value == 1 and last_button_state[3] == 1:
    last_button_state[3] = 0  


# +----------------+
# | MIDI functions |
# +----------------+

def get_tuning():
  return int(tuning[state_tune])

def get_velocity():
  return int(velocity[state_velocity])

def get_channel():
  return int(channel[state_channel])-1

def getNote(note):
  pitch = note + config.MIDI_OFFSET
  pitch = pitch + get_tuning()
  pitch = pitch + (12 * state_octave)
  return pitch

def playNote(in_pitch):
  if output_enable:
    midi.send(NoteOn(getNote(in_pitch), get_velocity()), get_channel())

def releaseNote(in_pitch):
  midi.send(NoteOff(getNote(in_pitch), 0), get_channel())

def testScale(note):
  if scale_map[state_scale][note] == 1:
    playNote(note)
  elif scale_map[state_scale][note] == 0 and note_active[note] == 1:
    releaseNote(note)

def sustainOn():
  midi.send(ControlChange(64, 127), get_channel())

def sustainOff():
  midi.send(ControlChange(64, 0), get_channel())

def modChange(mod):
  midi.send(ControlChange(1, mod), get_channel())

def bend(bend_val):
  midi.send(PitchBend(int(bend_val)), get_channel())


# +-------------------------------+
# | Async MIDI controls read cycle |
# +-------------------------------+

def test_midi_controls():
  global last_octave_up, last_octave_down, last_bend, last_mod, last_sustain
  global current_octave, state_octave
  current_octave_button_up = button_oct_up.value
  if last_octave_up == 0 and current_octave_button_up == 0:
    current_octave = current_octave + 1
    if current_octave > config.MAX_OCTAVE:
      current_octave = config.MAX_OCTAVE
    state_octave = current_octave
    last_octave_up = 1
  if last_octave_up == 1 and current_octave_button_up == 1:
    last_octave_up = 0
  
  current_octave_button_dn = button_oct_dn.value
  if last_octave_down == 0 and current_octave_button_dn == 0:
    current_octave=  current_octave - 1
    if current_octave < config.MIN_OCTAVE:
      current_octave = config.MIN_OCTAVE
    state_octave = current_octave
    last_octave_down = 1
  if last_octave_down == 1 and current_octave_button_dn == 1:
    last_octave_down = 0

  current_sustain = button_stn.value
  if last_sustain == 0 and current_sustain == 0:
    sustainOn()
    last_sustain = 1
  if last_sustain == 1 and current_sustain == 1:
    sustainOff()
    last_sustain = 0

  # Read pots and send mod / bend commands
  mod_value = 32768 - (mod_in.value/2)
  if (mod_value != last_mod) and abs(mod_value - last_mod) > config.IGNORE_JITTER:
    last_mod = mod_value
    conv_mod_value = int(abs(mod_value - 16384)/128)
    modChange(conv_mod_value)

  bend_value = int(32768 - (bend_in.value/2))
  if (bend_value != last_bend) and abs(bend_value - last_bend) > config.IGNORE_JITTER:
    last_bend = bend_value
    bend(bend_value/2)

################################
# This is the main entry point #
################################

# Initial setup stuff and boot sequence
baseline_out.duty_cycle = config.INITIAL_BASELINE
output_enable = False
show_splash()
calibrate()
show_menu(main_menu,main_menu.pointer)

# Loop forever...
while True:
  output_enable = True  # Ignore note generation for the setup cycle
  test_menu_buttons()
  scanMatrix()
  test_midi_controls()

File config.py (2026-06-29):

# eHarp in CircuitPython

# +-------------------------------+
# |   *** eHarp v2.0 Project ***  |
# |                               |
# | Author:         Gil Metcalf   |
# | Code version:   2.10.8        |
# | Date:           28-Jun-2026   |
# | Licence :       GPL v3.0      |
# +-------------------------------+

# Externalised config elements

# Scanning constants
NUM_NOTES = 32              # Number of notes avaiable on the eHarp
NUM_ROWS = 6                # Number of laser anodes to scan in matrix
NUM_COLS = 6                # Number of laser cathodes to scan in matrix
NOTE_ON_LOGIC = True        # input state for "on" note
LASER_SETTLE = 0.0025        # Settle time between laser on and reading input

# Calibration and diagnostics constants
CALIBRATION_SCANS = 10      # Number of scans for calibration cycle
SLOW_SCAN_COUNT = 5         # Number of cycles for slow scan
SLOW_SCAN_SPEED = 0.25      # Number of seconds for each step in slow scan
DCMV_RATIO = 10             # FITA duty cycle to mV ration for baseline control
BASE_OFFSET = 20            # Offset to set baseline value. Should be slightly above 0mV
BASE_SETTLE = 0.01          # Baseline ADC settle time in seconds
INITIAL_BASELINE = 150      # Initial baseline output value on boot
MAX_MUTE_TIME = 60          # Maximum seconds lasers can be muted for

# MIDI constants
MIDI_OFFSET = 48            # MIDI number for lowest note
IGNORE_JITTER = 500         # Threshold for bend/mod ADC change detection
MAX_OCTAVE = 3              # Maximum allowed octave setting
MIN_OCTAVE = -3             # Minimum allowed octave setting

# Display constants
DISPLAY_WIDTH = 128         # Display width in pixels
DISPLAY_HEIGHT = 128        # Display height in pixels
DISPLAY_OFFSET = 0          # Prevents display wrapping oddly (specific to oLED display)
DISPLAY_ROTATION = 180      # Spins display to show correctly on panel
DISPLAY_WINDOW = 10         # Maximum number of lines of text to display
SPLASH_TIME = 6             # Maximum number of seconds splashscreen will display
LOGO_FILE = "/logo.bmp"      # Logo file for splash screen

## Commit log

2025-03-26 Set row and column parameters correctly
    [code.py]
2025-03-26 Small change to claculate notes correctly
    [code.py]
2026-04-18 Baseline implementation
    [laser_driver.kicad_sch]
2026-06-16 Lopts and lots of changes for new body and circuitry
    [dual_panel.FCStd, eHarp_schematics_MIDIboard.kicad_sch, eHarp_schematics_displayboard.kicad_sch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]
2026-06-17 Updates for variable numbers of lasers. Removed redundant commented code. Addded scan test code
2026-06-17 Corrected laser_enable placing
2026-06-18 fixed some display issues with splashscreen, and added "press any button" capability to exit splash.
    [code.py]
2026-06-19 Added single step function. Consolidated cell selection and laser control into one function.
2026-06-24 New menu system; new code for baseline management, updated schematics
    [eHarp_sschematics_mainboard.kicad_sch, eHarp_sschematics_mainboard.recovered.2026-06-22_154934.kicad_sch]
2026-06-28 Added schematics PDF
2026-06-29 General cleanup and added some design files
    [dual_panel.FCStd, eHarp_schematics_MIDIboard.kicad_sch, eHarp_schematics_displayboard.kicad_sch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]
